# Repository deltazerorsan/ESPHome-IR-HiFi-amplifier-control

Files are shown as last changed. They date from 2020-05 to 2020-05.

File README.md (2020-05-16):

# ESPHome IR HiFi amplifier control
The goal is to remote control the volume, a standard knob managing a potentiometer, and also switch the HiFi amplifier on and off.

The project is based on an ESP32 and ESPHome, to receive and decode the IR from a remote control. It can use any remote with a few minor adjustements.

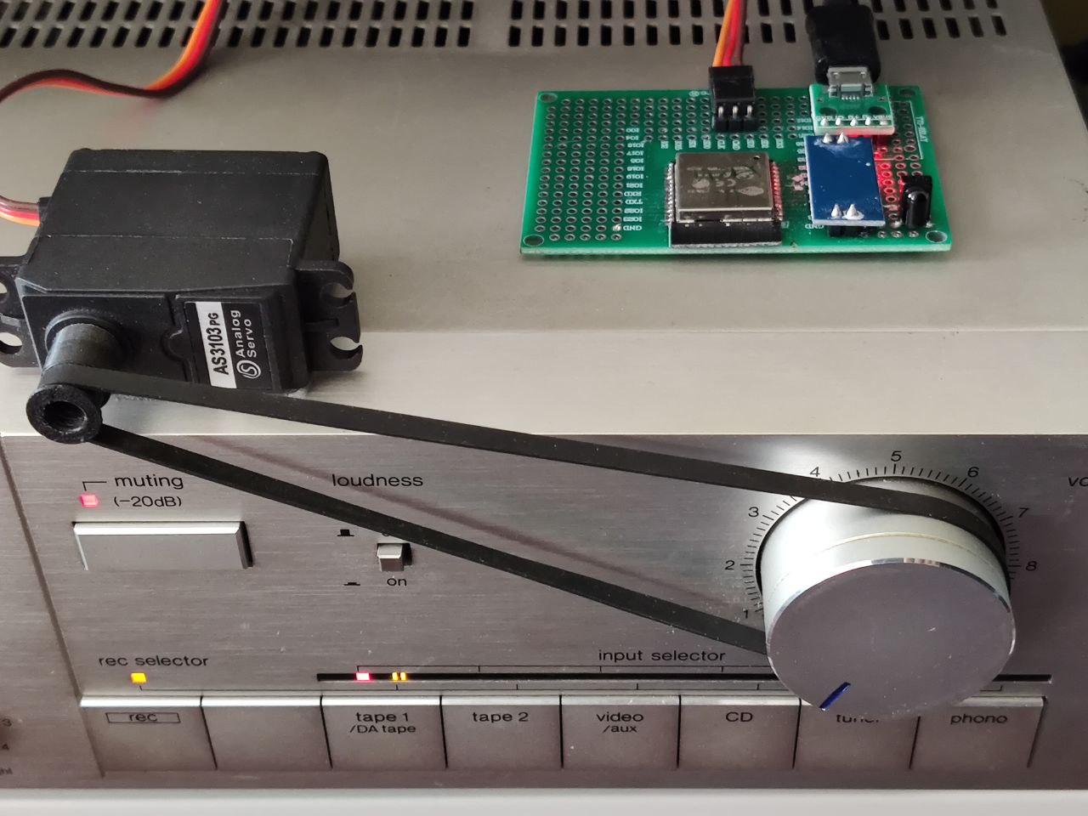
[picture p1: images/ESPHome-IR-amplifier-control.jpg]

The servo and the board are fixed with double sided tape, so everything is removable.

For the ON/OFF the project uses a Shelly Plug S managed via web from Node-RED. One of the keys of the remote is decoded and triggers a MQTT message that Node-RED can capture and convert to a relay toggle order for the Shelly Plug. Of course any other smart plug can be used if it accepts commands via web.

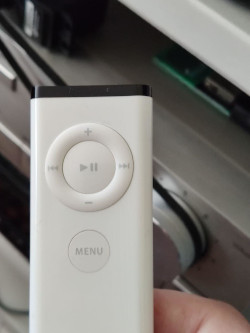
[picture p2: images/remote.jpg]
 

The remote used and the servo pulley (servo_pulley.stl included)

So, the project needs:

- TSOP38238 to receive infrared signals
- ESP-WROOM-32 module (or any board with similar module)
- 360 degrees small servo (not a standard one, but 360 degrees)
- Appropriate belt
- some 3.3 power source
  - 5 volts to 3.3 converter (it can be onboard)
  - Wall 5 volts power supply (or something equivalent)
- Any smart plug like Shelly Plug S or similar

Infrastructure:

- WiFi network
- ESPHome running (in my case Hassio version)
- Node-RED running (in my case Hassio version)



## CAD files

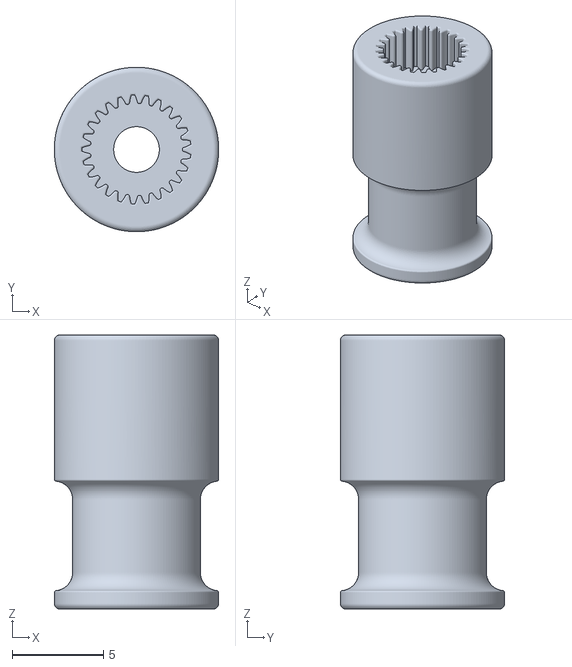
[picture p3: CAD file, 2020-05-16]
ESPHome_yaml/servo_pulley.stl
9.00 x 9.00 x 15.0

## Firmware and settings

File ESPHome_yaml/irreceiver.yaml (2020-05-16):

substitutions:
  devicename: irreceiver
  uper_devicename: IR Receiver
  device_ip: 192.168.1.33

esphome:
  name: $devicename
  platform: ESP32
  board: esp-wrover-kit

  on_boot:
    priority: -10
    then:
      - servo.write:
          id: my_servo
          level: 0                   # put the servo in neutral (stoped)
      - delay: 100ms
      - servo.detach: my_servo       # always detach the servo to ensure it stops completely
      - lambda: 'id(my_global_timer) = millis();'

  on_loop:
    then:
      - if:
          condition:                 # this stops de servo after 300ms from a received order
            lambda: |-
              if ((millis() > (id(my_global_timer) + 300)) and (id(my_global_attach))) {
                id(my_global_attach) = false;
                return true;
              } else {
                return false;
              }
          then:
            - servo.write:
                id: my_servo
                level: 0
            - delay: 100ms
            - servo.detach: my_servo
            - lambda: 'ESP_LOGD("main", "Dettached");' # just to see in the logs that the timeout is working as expected

globals:
  - id: my_global_level                                # the value to pass to the servo
    type: float
    restore_value: no
    initial_value: '0'
  - id: my_global_timer                                # the time to control de 300ms timeout
    type: ulong
    restore_value: no
    initial_value: '1000000'
  - id: my_global_attach                               # just to know inside the on_loop if the servo is attached
    type: boolean
    restore_value: no
    initial_value: 'false'

wifi:
  networks:
    - ssid: !secret wifi2_ssid
      password: !secret wifi_pass
    - ssid: !secret wifi_ssid
      password: !secret wifi_pass
    - ssid: !secret wifi3_ssid
      password: !secret wifi_pass
  manual_ip:
    static_ip: $device_ip
    gateway: 192.168.1.1
    subnet: 255.255.255.0
    dns1: !secret dns1
    dns2: !secret dns2

# Enable logging
logger:

# Enable Home Assistant API
api:
  password: !secret api_pass

ota:
  password: !secret ota_pass

mqtt:
  broker: !secret broker_ip

remote_receiver:
  pin:
    number: 32
    inverted: true
  dump: lg                         # you can comment this line out when every keys is known

  on_lg:
#                                  0.15 slow ccw rotation to lower the volume
#                                     1 fast ccw rotation to fast lower the volume
#                                 -0.15 slow cw rotation to raise the volume
#                                     0 for later use to send mqtt message 
    then:
      - lambda: 'id(my_global_timer) = millis();'
      - lambda: 'id(my_global_attach) = true;'
      - servo.write:
          id: my_servo
          level: !lambda |-
            switch (x.data) {
              case 2011279369:
                id(my_global_level) = 0.15;
                return id(my_global_level);
              case 2011242505:
                id(my_global_level) = 1;
                return id(my_global_level);
              case 2011287561:
                id(my_global_level) = -0.15;
                return id(my_global_level);
              case 2011250697:
                id(my_global_level) = 0;
                return id(my_global_level);
              default:
                id(my_global_level) = 1;
                return 0;
            }
      - lambda: 'ESP_LOGD("main", "x = %d", x.data);'                             # show the code of the remote key pressed
      - lambda: 'ESP_LOGD("main", "my_global_level = %f", id(my_global_level));'  # show the value passed to the servo
      - if:
          condition:                                                              # uses the 0 value to trigger the mqtt message
            lambda: |-
              if (id(my_global_level) == 0) {
                return true;
              } else {
                return false;
              }
          then:
            - mqtt.publish:
                topic: Amplificador/SW1                                           # this topic is the one used in Node-RED
                payload: "SW"
            - lambda: 'ESP_LOGD("main", "SW = %f", id(my_global_level));'

servo:
  - id: my_servo
    output: pwm_output
    idle_level: 7.40%     # those three values depend on your servo
    min_level: 6%         # you must adjust it by trial and error
    max_level: 9.5%       # until the servo stops BEFORE the detach
    
output:
  - platform: ledc
    id: pwm_output
    pin: 12               # adapt to your needs
    frequency: 50 Hz
